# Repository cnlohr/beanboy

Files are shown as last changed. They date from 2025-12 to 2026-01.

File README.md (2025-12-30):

# beanboy

The beanboy is a handheld game system with 3 buttons, and an oled display.  It has the following specs:
 * Powered by a 9V Battery
 * 128x128 RB150-2828KSWKG01 SPI OLED display from Ronboe ($2.50)
 * 3 Silicone buttons with pressure sensitivity
 * TBD: Runtime
 * CH572 Main Processor
   * 240kB Flash
   * 12kB RAM
   * 60MHz
   * RISC-V rv32imbc processor
   * 2.4GHz iSLER radio comms

(Early drafts, not ready yet)

## Installation / getting started

Follow these instructions: [https://github.com/cnlohr/ch32fun/wiki](https://github.com/cnlohr/ch32fun/wiki)

## Graphics API

The bean boy uses a monochrome 128x128 display.

### Input

You get "pressures" for button 1, button 2, button 3, and the battery level. (For now, just print the values to the screen, we will be changing the levels)

```c
	uint32_t pressures[4];
	BeanBoyReadPressures( pressures );
```

### Sprites

Have .png files in `sprites/` folder, then on compile, they will turn into the object name itself, when you say `make clean firmware.elf`

```c
void RenderBSprite( const bsprite * spr, int outx, int outy );
```

For instance if you have `sprites/bubble.png`, you can call:

```c
	RenderBSprite( &bubble, x, y );
```

You can use purple or actual transparency to indicate transparent, then use white or black.

### Basic Drawing

Graphics APIs are from [the ch32v003 ssd1306 driver](https://github.com/cnlohr/ch32fun/blob/master/extralibs/ssd1306.h)

```c
#define SSD1306_W 128
#define SSD1306_H 128

void ssd1306_drawPixel(uint32_t x, uint32_t y, int color);
void ssd1306_xorPixel(uint32_t x, uint32_t y);
void ssd1306_drawImage(uint32_t x, uint32_t y, const unsigned char* input, uint32_t width, uint32_t height, uint32_t color_mode);
void ssd1306_drawFastVLine(int32_t x, int32_t y, int32_t h, uint32_t color);
void ssd1306_drawFastHLine(uint32_t x, uint32_t y, uint32_t w, uint32_t color);
void ssd1306_drawLine(int x0, int y0, int x1, int y1, uint32_t color);
void ssd1306_drawCircle(int x, int y, int radius, int color);
void ssd1306_fillCircle(int x, int y, int radius, int color);
void ssd1306_drawRect(int32_t x, int32_t y, uint32_t w, uint32_t h, uint32_t color);
void ssd1306_fillRect(uint32_t x, uint32_t y, uint8_t w, uint32_t h, uint32_t color);
void ssd1306_xorrect(uint8_t x, uint8_t y, uint8_t w, uint8_t h);
void ssd1306_drawchar(uint8_t x, uint8_t y, uint8_t chr, uint8_t color);
void ssd1306_drawstr(uint8_t x, uint8_t y, char *str, uint8_t color);
void ssd1306_drawchar_sz(uint8_t x, uint8_t y, uint8_t chr, uint8_t color, font_size_t font_size);
void ssd1306_drawstr_sz(uint8_t x, uint8_t y, char *str, uint8_t color, font_size_t font_size);
```

### Wireless API

```c
// call these
void ISLERSetup( int channel ); 
void ISLERSend( uint8_t message, int messageLength );

struct MyGameStruct
{
	uint32_t id;
	uint8_t something;
} __attribute__((packed));

void ISLERCallback( uint8_t * txmac, uint8_t * message, int messageLength, int rssi )
{
	struct MyGameStruct * st = (struct MyGameStruct*)message;

	if( messageLength < sizeof( struct MyGameStruct ) )
		return;

	printf( "%d\n", st->something );
}

void main()
{
	ISLERSetup( 9 );

	struct MyGameStruct st;
	st.id = 0x1234778a; // Some ID so you don't get confused with other BLE-messages.
	st.something = 5;

	ISLERSend( &st, sizeof( st ) );
}
```

## TODO

TODO:

1. ~~Build up two beanboys~~
2. ~~Check to see if the radio code works.~~
3. ~~Make sprite import code.~~
4. ~~Add transparency code.~~
5. ~~Add API for comms~~
6. Add networking to emu
7. Add button debouncing
8. Add compression to sprites
9. Add sprite rotation maybe?
10. Add sprite scaling maybe?
11. "Pass the puffer"  "Hot Potato with puffer fish"
  a. Choose between 2 and 6 players
  b. Randomly assign X amount of passes.
  c. number of passes remaining is unknown.
12. Shut the box.
  a. Rules too complicated for me to write here.

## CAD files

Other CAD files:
firmware/test/teapot.obj
firmware/test/donut.obj
firmware/test/bunny.obj
firmware/test/bean.obj

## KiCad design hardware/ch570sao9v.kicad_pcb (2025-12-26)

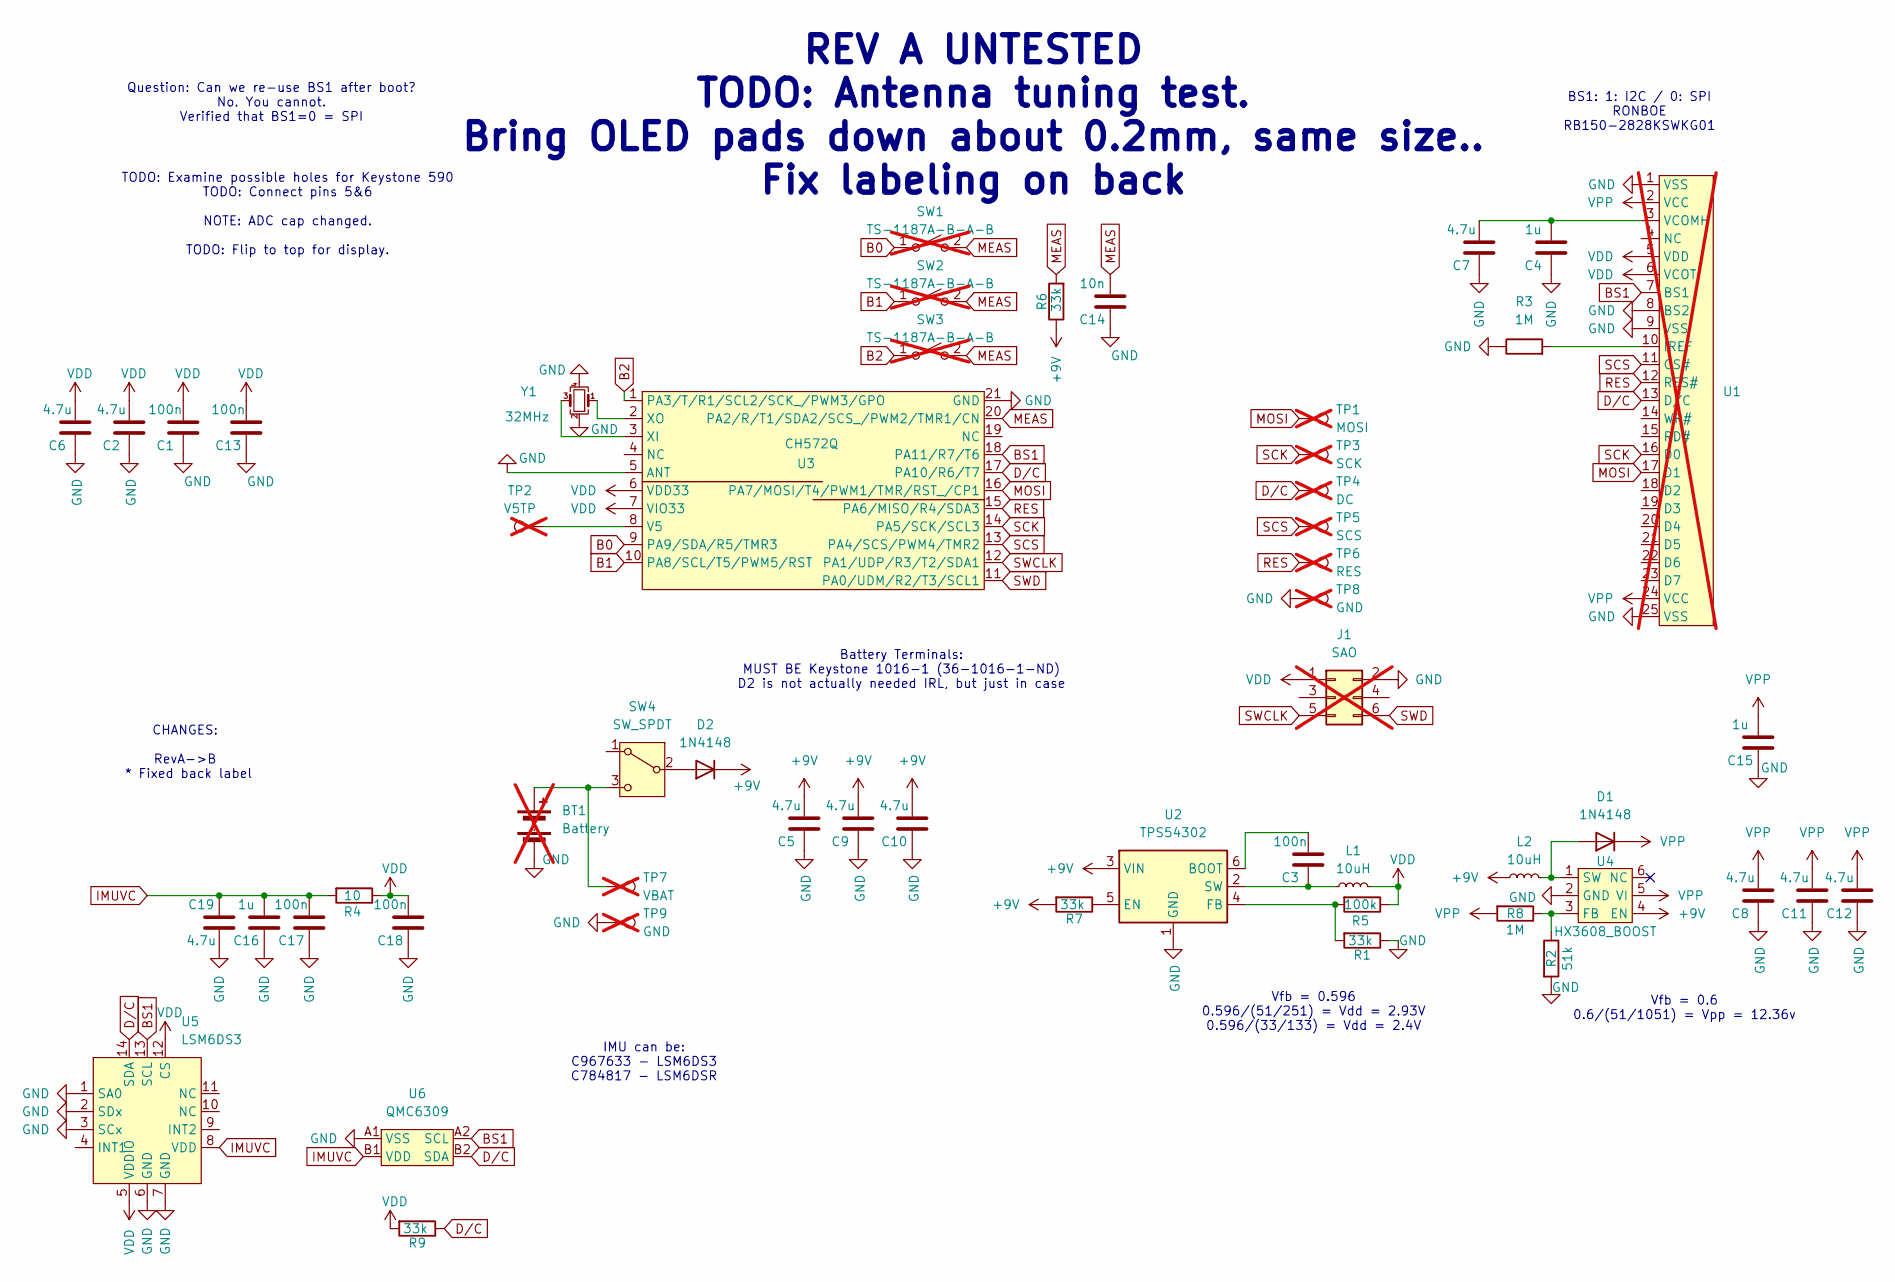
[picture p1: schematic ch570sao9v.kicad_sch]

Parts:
BT1: Battery; not fitted
C1, C3, C13, C17, C18: 100n; R_0402_1005Metric; LCSC C307331
C2, C5, C6, C7, C8, C9, C10, C11, C12, C19: 4.7u; C_1206_3216Metric; LCSC C29823
C4, C15, C16: 1u; R_0402_1005Metric; LCSC C52923
C14: 10n; R_0402_1005Metric; LCSC C15195
D1, D2: 1N4148; D_SOD-323; LCSC C2128
J1: SAO; PinHeader_2x03_P2.54mm_Vertical_SMD; not fitted
L1, L2: 10uH; L_1008_2520Metric; LCSC C37428
R1, R6, R7, R9: 33k; R_0402_1005Metric_COMPACT; LCSC C25779
R2: 51k; R_0402_1005Metric_COMPACT; LCSC C25794
R3, R8: 1M; R_0402_1005Metric_COMPACT; LCSC C26083
R4: 10; R_0402_1005Metric_COMPACT; LCSC C25077
R5: 100k; R_0402_1005Metric_COMPACT; LCSC C25741
SW1, SW2, SW3: TS-1187A-B-A-B; BTC007_Button_Silicone; not fitted
SW4: SW_SPDT; SW_SPDT_PCM12; LCSC C3008585
TP1: MOSI; TestPoint_Pad_D1.0mm; not fitted
TP2: V5TP; TestPoint_Pad_D1.0mm; not fitted
TP3: SCK; TestPoint_Pad_D1.0mm; not fitted
TP4: DC; TestPoint_Pad_D1.0mm; not fitted
TP5: SCS; TestPoint_Pad_D1.0mm; not fitted
TP6: RES; TestPoint_Pad_D1.0mm; not fitted
TP7: VBAT; TestPoint_Pad_D1.0mm; LCSC C6063943; not fitted
TP8: GND; TestPoint_Pad_D1.0mm; not fitted
TP9: GND; TestPoint_Pad_D1.0mm; LCSC C6063943; not fitted
U1: RB150-2828KSWKG01; not fitted
U2: TPS54302; SOT-23-6; LCSC C311983
U3: CH572Q; QFN-20-1EP_3x3mm_P0.4mm_EP1.65x1.65mm; LCSC C46597863
U4: HX3608_BOOST; SOT-23-6; LCSC C296278
U5: LSM6DS3; LGA-14_3x2.5mm_P0.5mm_LayoutBorder3x4y_EVEN_PADS; LCSC C784817
U6: QMC6309; WLP-4_0.83x0.83mm_P0.4mm; LCSC C5439871
Y1: 32MHz; Crystal_SMD_2016-4Pin_2.0x1.6mm; LCSC C37635323

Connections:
+9V: C5.1, C9.1, C10.1, D2.1 (K), L2.1, R6.1, R7.2, U2.3 (VIN), U4.4 (EN)
B0: SW1.1 (A), U3.9 (PA9/SDA/R5/TMR3)
B1: SW2.1 (A), U3.10 (PA8/SCL/T5/PWM5/RST)
B2: SW3.1 (A), U3.1 (PA3/T/R1/SCL2/SCK_/PWM3/GPO)
BS1: U1.7 (BS1), U3.18 (PA11/R7/T6), U5.13 (SCL), U6.A2 (SCL)
D/C: R9.1, TP4.1, U1.13 (D/C), U3.17 (PA10/R6/T7), U5.14 (SDA), U6.B2 (SDA)
GND: BT1.2 (-), C1.2, C2.2, C4.2, C5.2, C6.2, C7.2, C8.2, C9.2, C10.2, C11.2, C12.2, C13.2, C14.2, C15.2, C16.2, C17.2, C18.2, C19.1, J1.2, R1.1, R2.2, R3.1, TP8.1, TP9.1, U1.1 (VSS), U1.8 (BS2), U1.9 (VSS), U1.25 (VSS), U2.1 (GND), U3.5 (ANT), U3.21 (GND), U4.2 (GND), U5.1 (SA0), U5.2 (SDx), U5.3 (SCx), U5.6 (GND), U5.7 (GND), U6.A1 (VSS), Y1.2, Y1.4
IMUVC: C16.1, C17.1, C19.2, R4.2, U5.8 (VDD), U6.B1 (VDD)
MEAS: C14.1, R6.2, SW1.2 (B), SW2.2 (B), SW3.2 (B), U3.20 (PA2/R/T1/SDA2/SCS_/PWM2/TMR1/CN)
MOSI: TP1.1, U1.17 (D1), U3.16 (PA7/MOSI/T4/PWM1/TMR/RST_/CP1)
unnamed: BT1.1 (+), SW4.3 (C), TP7.1
unnamed: D1.2 (A), L2.2, U4.1 (SW)
unnamed: D2.2 (A), SW4.2 (B)
unnamed: R3.2, U1.10 (IREF)
unnamed: C4.1, C7.1, U1.3 (VCOMH)
unnamed: C3.1, U2.6 (BOOT)
unnamed: R7.1, U2.5 (EN)
unnamed: R1.2, R5.2, U2.4 (FB)
unnamed: C3.2, L1.1, U2.2 (SW)
unnamed: TP2.1, U3.8 (V5)
unnamed: U3.3 (XI), Y1.3
unnamed: U3.2 (XO), Y1.1
unnamed: R2.1, R8.1, U4.3 (FB)
RES: TP6.1, U1.12 (RES#), U3.15 (PA6/MISO/R4/SDA3)
SCK: TP3.1, U1.16 (D0), U3.14 (PA5/SCK/SCL3)
SCS: TP5.1, U1.11 (CS#), U3.13 (PA4/SCS/PWM4/TMR2)
SWCLK: J1.5, U3.12 (PA1/UDP/R3/T2/SDA1)
SWD: J1.6, U3.11 (PA0/UDM/R2/T3/SCL1)
VDD: C1.1, C2.1, C6.1, C13.1, C18.1, J1.1, L1.2, R4.1, R5.1, R9.2, U1.5 (VDD), U1.6 (VCOT), U3.6 (VDD33), U3.7 (VIO33), U5.5 (VDDIO), U5.12 (CS)
VPP: C8.1, C11.1, C12.1, C15.1, D1.1 (K), R8.2, U1.2 (VCC), U1.24 (VCC), U4.5 (VI)

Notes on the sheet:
REV A UNTESTED TODO: Antenna tuning test. Bring OLED pads down about 0.2mm, same size.. Fix labeling on back
TODO: Examine possible holes for Keystone 590 TODO: Connect pins 5&6 NOTE: ADC cap changed. TODO: Flip to top for display.
Question: Can we re-use BS1 after boot? No. You cannot. Verified that BS1=0 = SPI
IMU can be: C967633 - LSM6DS3 C784817 - LSM6DSR
Vfb = 0.596 0.596/(51/251) = Vdd = 2.93V 0.596/(33/133) = Vdd = 2.4V
Vfb = 0.6 0.6/(51/1051) = Vpp = 12.36v
CHANGES: RevA->B * Fixed back label
Battery Terminals: MUST BE Keystone 1016-1 (36-1016-1-ND) D2 is not actually needed IRL, but just in case
BS1: 1: I2C / 0: SPI RONBOE RB150-2828KSWKG01

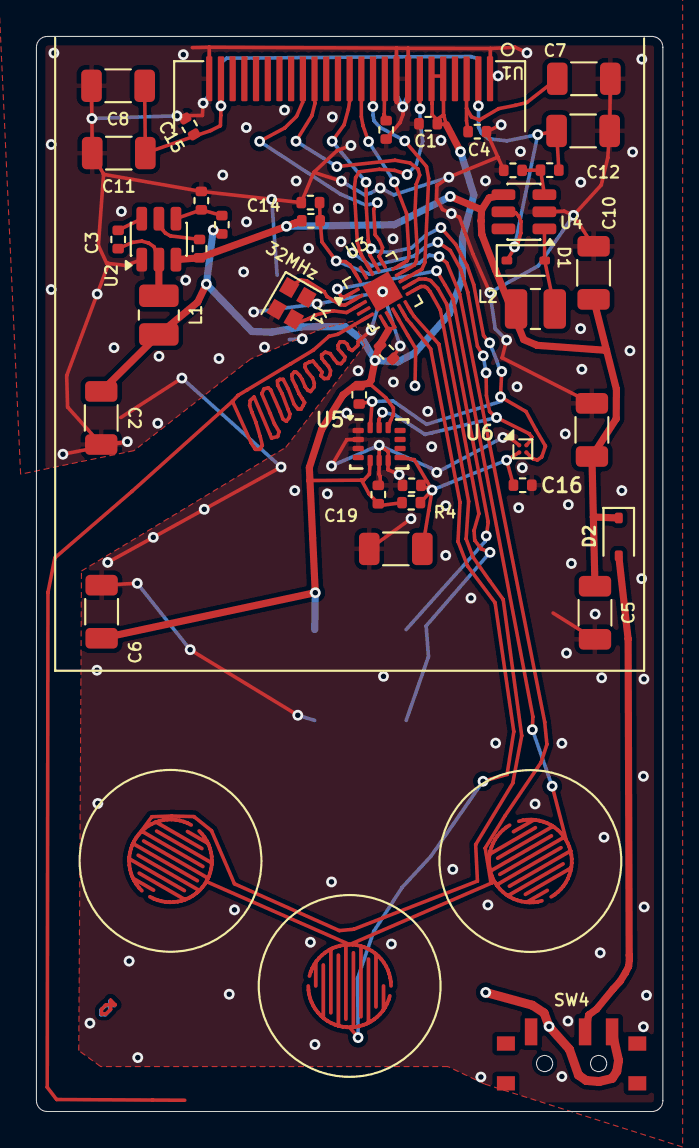
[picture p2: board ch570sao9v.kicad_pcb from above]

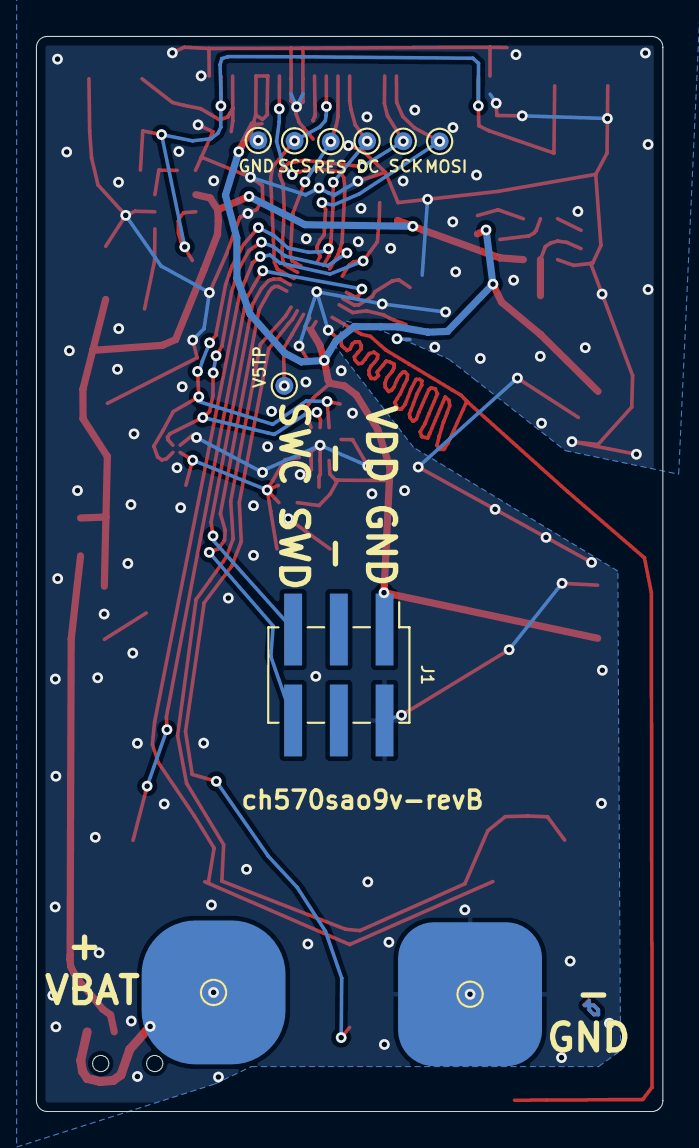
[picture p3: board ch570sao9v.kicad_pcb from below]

Board: 2 copper layers, 34.8 x 59.7 mm, 53 parts (10 on the bottom side), 30 nets.

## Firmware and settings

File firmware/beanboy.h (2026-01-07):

#ifndef _BEANBOY_H
#define _BEANBOY_H

// Forward declaration to push code into __HIGH_CODE which is really fast.
void ssd1306_drawPixel(uint32_t x, uint32_t y, int color) __HIGH_CODE;


#include "fixedmath.h"

/////////////////////////////////////////////////////////////////////////////////////////////////
/////////////////////////////////////////////////////////////////////////////////////////////////
// misc functions.

static inline void Reboot() __attribute__((noreturn));
static inline void Reboot()
{
	asm volatile( ".option push\n.option norelax\njr x0\n.option pop" );
	__builtin_unreachable();
}


/////////////////////////////////////////////////////////////////////////////////////////////////
/////////////////////////////////////////////////////////////////////////////////////////////////
// iSLER support
//
// BLE-like interface.

#if 0

#define ISLER_CALLBACK ISLER_BEANBOY_INTERNAL_CALLBACK
static void ISLER_BEANBOY_INTERNAL_CALLBACK();
#include "iSLER.h"
#define PHY_MODE       PHY_1M
#define ACCESS_ADDRESS 0x8E89BED6 // the "BED6" address for BLE advertisements

void ISLERCallback( uint8_t * txmac, uint8_t * message, int messageLength, int rssi );

uint8_t iSLERChannel;

static void ISLER_BEANBOY_INTERNAL_CALLBACK()
{
	// The chip stores the incoming frame in LLE_BUF, defined in extralibs/iSLER.h
	uint8_t *frame = (uint8_t*)LLE_BUF;
	if( !iSLERCRCOK() ) return;

	int rssi = ReadRSSI();
	int len = frame[0];
	ISLERCallback( frame+2, frame+10, len+4, rssi );
}

static void ISLERSetup( int channel )
{
	iSLERChannel = channel;
	RFCoreInit(LL_TX_POWER_6_DBM);
	Frame_RX(ACCESS_ADDRESS, channel, PHY_MODE);
}

static void ISLERSend( const void * message, int messageLength )
{
	__attribute__((aligned(4)))  uint8_t pkt_tx[messageLength+10];
	pkt_tx[0] = 0x02;
	pkt_tx[1] = 10+messageLength;
	memcpy( pkt_tx+2, (uint32_t*)ROM_CFG_MAC_ADDR, 6 );
	//memset( pkt_tx+2, 0xff, 6 );
	pkt_tx[8] = 0xff; // Normally should be 0x03, 0x19, 0x00, 0x00 for BLE
	pkt_tx[9] = 0xff; 
	memcpy( pkt_tx+10, message, messageLength );

	Frame_TX(ACCESS_ADDRESS, pkt_tx, messageLength+10, iSLERChannel, PHY_MODE);
	Frame_RX(ACCESS_ADDRESS, iSLERChannel, PHY_MODE);
}


#endif



const uint8_t * GetSelfMAC() { return (const uint8_t*)ROM_CFG_MAC_ADDR; }


/////////////////////////////////////////////////////////////////////////////////////////////////
/////////////////////////////////////////////////////////////////////////////////////////////////
// Auxiliary rendering sources bsprite
//
// This drawing function is very slow.  Consider optimizing.
//
static void RenderBSprite( const bsprite * spr, int outx, int outy ) __attribute__ ((noinline));
static void RenderBSprite( const bsprite * spr, int outx, int outy )
{
	int sw = spr->w;
	int sh = spr->h;
	int x, y;
	const uint32_t * bin = &spr->data[0];
	for( y = 0; y < sh; y++, outy++ )
	{
		uint8_t * bout = &ssd1306_buffer[(outy>>3)*SSD1306_W + outx];
		int boutshift = outy&7;
		int boutshiftmaskinv = ~(1<<boutshift);
		int tx = outx;
		int group;
		if( outy < 0 )
		{
			bin += sw;
			continue;
		}
		else if( outy >= SSD1306_H )
		{
			break;
		}

		for( group = 0; group < sw; group++ )
		{
			uint32_t input = *(bin++);
			for( x = 0; x < 16; x++, tx++, input >>= 1 )
			{
				if( tx < 0 || tx >= SSD1306_W ) continue;
				if( input & 1 )
				{
					bout[x] = ( bout[x] & boutshiftmaskinv ) | (((input>>16)&1)<< ( boutshift));
				}
			}
			bout += 16;
		}
	}
}
/////////////////////////////////////////////////////////////////////////////////////////////////
/////////////////////////////////////////////////////////////////////////////////////////////////
// FakeDC
//
// Fake digital-to-analog, by looking at the time constant on a capcaitor
// and waiting for the scmitt trigger flip.
//

#define CAPACITANCE 0.00000001
#define RESISTANCE  33000.0
#define VREF 1.75
#define FIXEDPOINT_SCALE 100

volatile uint32_t lastfifo = 0;
volatile uint32_t frameentropy = 0;

void TMR1_IRQHandler(void) __attribute__((interrupt))  __attribute__((section(".highcode")));
void TMR1_IRQHandler(void)
{
	R8_TMR_INT_FLAG = 2;
	lastfifo = R32_TMR_FIFO;
	funPinMode( PA2, GPIO_ModeOut_PP_20mA );
}


// The timing on the setup has to be tight.
void EventRelease(void) __attribute__((section(".highcode"))) __attribute__((noinline));
void EventRelease(void)
{
	R8_TMR_CTRL_MOD = 0b00000010; // Reset Timer
	R8_TMR_CTRL_MOD = 0b11000101; // Capture mode rising edge
	funPinMode( PA2, GPIO_ModeIN_Floating );
}

static void SetupADC(void)
{
	R8_TMR_CTRL_MOD = 0b00000010; // All clear
	R32_TMR_CNT_END = 0x03FFFFFF; // Maximum possible counter size.
	R8_TMR_CTRL_MOD = 0b11000101; // Capture mode rising edge
	R8_TMR_INTER_EN = 0b10; // Capture event.

	R16_PIN_ALTERNATE_H |= 1<<6; // Map PA2 to CAP1 (could be PA7, PA4, or PA9) (see RB_TMR_PIN)

	NVIC_EnableIRQ(TMR1_IRQn);
	__enable_irq();

	funPinMode( PA2, GPIO_ModeOut_PP_20mA );
}

static void BeanBoyReadPressures( uint32_t * pressures )
{
	int btn = 0;
	for( btn = 0; btn < 4; btn++ )
	{
		// try GPIO_CFGLR_IN_PUPD, GPIO_ModeIN_Floating, GPIO_CFGLR_OUT_10Mhz_PP as well
		funPinMode( PA3, GPIO_ModeIN_Floating );
		funPinMode( PA8, GPIO_ModeIN_Floating );
		funPinMode( PA9, GPIO_ModeIN_Floating );
		switch( btn )
		{
		case 0:
			funPinMode( PA8, GPIO_CFGLR_OUT_10Mhz_PP );
			funDigitalWrite( PA3, 1 );
			break;
		case 1:
			funPinMode( PA9, GPIO_CFGLR_OUT_10Mhz_PP );
			funDigitalWrite( PA8, 1 );
			break;
		case 2:
			funPinMode( PA3, GPIO_CFGLR_OUT_10Mhz_PP );
			funDigitalWrite( PA9, 1 );
			break;
		}

		uint32_t p;

		if( *((uint32_t*)0x4fff0000) == 0xaaaaaaaa )
		{
			p = *((uint32_t*)(0x4fff0004+4*btn));
		}
		else
		{
			lastfifo = 0;
			EventRelease();
			int to = 4000;
			while( !lastfifo && --to );

			#define COEFFICIENT (const uint32_t)(FUNCONF_SYSTEM_CORE_CLOCK*(RESISTANCE*CAPACITANCE)*VREF*FIXEDPOINT_SCALE+0.5)
			int r = lastfifo - 2; // 2 cycles back.
			int vtot = COEFFICIENT/r + ((const uint32_t)(VREF*FIXEDPOINT_SCALE));
			p = vtot - 70;
		}

		pressures[btn] = p;

		// Junky entropy.
		uint32_t fe = frameentropy;
		fe += p;
		fe ^= fe << 10;
		fe ^= fe << 21;
		frameentropy = fe;
	}
}

/////////////////////////////////////////////////////////////////////////////////////////////////


#define PIN_SDA PA10
#define PIN_SCL PA11
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

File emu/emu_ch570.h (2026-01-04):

#ifndef _CORE_H
#define _CORE_H

#include <stdint.h>

// For functions in this code.
uint32_t GetSTK(void);

//==============================================================================
// mini-rv32ima augmentations.
//==============================================================================

static inline void* ch570threadFn(void* v);
static inline uint32_t MINIRV32_LOAD4s(uint32_t ofs, uint32_t* rval, uint32_t* trap);
static inline uint16_t MINIRV32_LOAD2s(uint32_t ofs, uint32_t* rval, uint32_t* trap);
static inline uint8_t MINIRV32_LOAD1s(uint32_t ofs, uint32_t* rval, uint32_t* trap);
static inline int16_t MINIRV32_LOAD2_SIGNEDs(uint32_t ofs, uint32_t* rval, uint32_t* trap);
static inline int8_t MINIRV32_LOAD1_SIGNEDs(uint32_t ofs, uint32_t* rval, uint32_t* trap);

#define RAM_SIZE   0x3000
#define FLASH_SIZE 0x40000

extern uint32_t R32_PA_PU;
extern uint32_t R32_PA_PD_DRV;
extern uint32_t R32_PA_DIR;
extern uint32_t R32_PA_OUT;
extern uint32_t R32_PFIC_IENR1;
extern volatile int ch570runMode;
extern uint8_t ch570flash[FLASH_SIZE];
extern uint8_t ch570ram[RAM_SIZE];
extern struct MiniRV32IMAState ch570state;
extern volatile uint32_t pressures[4];

void Handle_R8_TMR_CTRL_MOD( uint8_t regset );
void Handle_R8_SPI_BUFFER( uint8_t regset );


uint32_t debugpc; // Debug PC

static int CHPLoad(uint32_t address, uint32_t* regret, int size);
static int CHPStore(uint32_t address, uint32_t regret, int size);

#define MINI_RV32_RAM_SIZE		(0x20000000 + RAM_SIZE)
#define MINIRV32_RAM_IMAGE_OFFSET 0x00000000
#define MINIRV32WARN(x...)		fprintf(stderr, x)
#define MINIRV32_MMIO_RANGE(n)	((0x40000000 <= (n) && (n) < 0x50000000)) || (0xe0000000 <= (n) && (n) < 0xe000ffff)

// These should not be accessable.
#define MINIRV32_HANDLE_MEM_STORE_CONTROL(addy, val) CHPStore(addy, val, 4);
#define MINIRV32_HANDLE_MEM_LOAD_CONTROL(addy, val)  CHPLoad(addy, &val, 4);

#define RAMOFS 0x20000000

#define MINIRV32_CUSTOM_MEMORY_BUS

#define MINIRV32_STORE4(ofs, val)						  \
	if (ofs < FLASH_SIZE - 3)							  \
	{													  \
		*(uint32_t*)(ch570flash + ofs) = val;		   \
	}													  \
	else if (ofs >= RAMOFS && ofs < RAMOFS + RAM_SIZE - 3) \
	{													  \
		*(uint32_t*)(ch570ram + ofs - RAMOFS) = val;	\
	}													  \
	else												   \
	{													  \
		if (CHPStore(ofs, val, 4))						 \
		{												  \
			trap = (7 + 1);								\
			rval = ofs;									\
		}												  \
	}
#define MINIRV32_STORE2(ofs, val)						  \
	if (ofs < FLASH_SIZE - 1)							  \
	{													  \
		*(uint16_t*)(ch570flash + ofs) = val;		   \
	}													  \
	else if (ofs >= RAMOFS && ofs < RAMOFS + RAM_SIZE - 1) \
	{													  \
		*(uint16_t*)(ch570ram + ofs - RAMOFS) = val;	\
	}													  \
	else												   \
	{													  \
		if (CHPStore(ofs, val, 2))						 \
		{												  \
			trap = (7 + 1);								\
			rval = ofs;									\
		}												  \
	}
#define MINIRV32_STORE1(ofs, val)						  \
   { \
	if (ofs < FLASH_SIZE - 0)							  \
	{													  \
		*(uint8_t*)(ch570flash + ofs) = val;			\
	}													  \
	else if (ofs >= RAMOFS && ofs < RAMOFS + RAM_SIZE - 0) \
	{													  \
		*(uint8_t*)(ch570ram + ofs - RAMOFS) = val;	 \
	}													  \
	else												   \
	{													  \
		if (CHPStore(ofs, val, 1))						 \
		{												  \
			trap = (7 + 1);								\
			rval = ofs;									\
		}												  \
	} }
static inline uint32_t MINIRV32_LOAD4s(uint32_t ofs, uint32_t* rval, uint32_t* trap)
{
	uint32_t tmp = 0;
	if (ofs < FLASH_SIZE - 3)
	{
		tmp = *(uint32_t*)(ch570flash + ofs);
	}
	else if (ofs >= RAMOFS && ofs < RAMOFS + RAM_SIZE - 3)
	{
		tmp = *(uint32_t*)(ch570ram + ofs - RAMOFS);
	}
	else
	{
		if (CHPLoad(ofs, &tmp, 4))
		{
			*trap = (7 + 1);
			*rval = ofs;
		}
	}
	return tmp;
}
static inline uint16_t MINIRV32_LOAD2s(uint32_t ofs, uint32_t* rval, uint32_t* trap)
{
	uint16_t tmp = 0;
	if (ofs < FLASH_SIZE - 1)
	{
		tmp = *(uint16_t*)(ch570flash + ofs);
	}
	else if (ofs >= RAMOFS && ofs < RAMOFS + RAM_SIZE - 1)
	{
		tmp = *(uint16_t*)(ch570ram + ofs - RAMOFS);
	}
	else
	{
		if (CHPLoad(ofs, (uint32_t*)&tmp, 2))
		{
			*trap = (7 + 1);
			*rval = ofs;
		}
	}
	return tmp;
}
static inline uint8_t MINIRV32_LOAD1s(uint32_t ofs, uint32_t* rval, uint32_t* trap)
{
	uint8_t tmp = 0;
	if (ofs < FLASH_SIZE - 0)
	{
		tmp = *(uint8_t*)(ch570flash + ofs);
	}
	else if (ofs >= RAMOFS && ofs < RAMOFS + RAM_SIZE - 0)
	{
		tmp = *(uint8_t*)(ch570ram + ofs - RAMOFS);
	}
	else
	{
		if (CHPLoad(ofs, (uint32_t*)&tmp, 1))
		{
			*trap = (7 + 1);
			*rval = ofs;
		}
	}
	return tmp;
}
static inline int16_t MINIRV32_LOAD2_SIGNEDs(uint32_t ofs, uint32_t* rval, uint32_t* trap)
{
	int16_t tmp = 0;
	if (ofs < FLASH_SIZE - 1)
	{
		tmp = *(int16_t*)(ch570flash + ofs);
	}
	else if (ofs >= RAMOFS && ofs < RAMOFS + RAM_SIZE - 1)
	{
		tmp = *(int16_t*)(ch570ram + ofs - RAMOFS);
	}
	else
	{
		if (CHPLoad(ofs, (uint32_t*)&tmp, -2))
		{
			*trap = (7 + 1);
			*rval = ofs;
		}
	}
	return tmp;
}
static inline int8_t MINIRV32_LOAD1_SIGNEDs(uint32_t ofs, uint32_t* rval, uint32_t* trap)
{
	int8_t tmp = 0;
	if (ofs < FLASH_SIZE - 0)
	{
		tmp = *(int8_t*)(ch570flash + ofs);
	}
	else if (ofs >= RAMOFS && ofs < RAMOFS + RAM_SIZE - 0)
	{
		tmp = *(int8_t*)(ch570ram + ofs - RAMOFS);
	}
	else
	{
		if (CHPLoad(ofs, (uint32_t*)&tmp, -1))
		{
			*trap = (7 + 1);
			*rval = ofs;
		}
	}
	return tmp;
}

#define MINIRV32_LOAD4(ofs)		MINIRV32_LOAD4s(ofs, &rval, &trap)
#define MINIRV32_LOAD2(ofs)		MINIRV32_LOAD2s(ofs, &rval, &trap)
#define MINIRV32_LOAD1(ofs)		MINIRV32_LOAD1s(ofs, &rval, &trap)
#define MINIRV32_LOAD2_SIGNED(ofs) MINIRV32_LOAD2_SIGNEDs(ofs, &rval, &trap)
#define MINIRV32_LOAD1_SIGNED(ofs) MINIRV32_LOAD1_SIGNEDs(ofs, &rval, &trap)

#define MINIRV32_HANDLE_TRAP_PC									 \
	switch (CSR(mtvec) & 3)										 \
	{															   \
		case 2:													 \
		case 0:													 \
			pc = (CSR(mtvec) - 4);								  \
			break;												  \
		case 1:													 \
			pc = (((CSR(mtvec) & ~3) + 4 * CSR(mcause)) - 4);	   \
			break;												  \
		case 3:													 \
			pc = ((MINIRV32_LOAD4((CSR(mtvec) & ~3) + 4 * 3)) /* - 4  I thought we needed this */); \
			break;												  \
	}

#define MINIRV32_ALIGNMENT 1

#define MINIRV32_IMPLEMENTATION

// https://riscv.github.io/riscv-isa-manual/snapshot/unprivileged/#_compressed_instruction_formats about 1/3 the way
// down. https://www.cs.sfu.ca/~ashriram/Courses/CS295/assets/notebooks/RISCV/RISCV_CARD.pdf
// This adds -C extension support to mini-rv32ima.
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

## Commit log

2025-12-07 Add skeleton project
    [ch570sao9v.kicad_pcb, ch570sao9v.kicad_sch]
2025-12-07 Update design
    [ch570sao9v.kicad_pcb, ch570sao9v.kicad_sch]
2025-12-11 Update to rev a
    [ch570sao9v.kicad_pcb, ch570sao9v.kicad_sch]
2025-12-12 Update rev a
    [ch570sao9v.kicad_pcb, ch570sao9v.kicad_sch]
2025-12-25 Bump design
    [ch570sao9v.kicad_pcb, ch570sao9v.kicad_sch]
2025-12-26 Update firmware with I2C stuff
2025-12-26 Add bean boy rev B
    [ch570sao9v.kicad_pcb]
2025-12-30 1. Update my stuff 2. Fix delta time
    [beanboy.h, custom_i2c.h, firmware.c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]
2025-12-31 Update system to enable wireless comms
2026-01-04 Working IMU math
2026-01-04 Oope switch menu back + I think my mode is done
2026-01-04 * Fix graphics performance * Make IMU work for example apps
    [bean.obj, bunny.obj]
2026-01-04 Remove extra printf
2026-01-04 Fixup some bugs in the IMU code and improve performance
    [beanboy.h, firmware.c, mode_test.h]
2026-01-05 Add donut to models
    [donut.obj]
2026-01-05 Groundwork laid for blackjack
2026-01-05 Update mode test with teapot
    [teapot.obj]
2026-01-05 Dunno why but resetting caused issues for the OLED
    [mode_test.h]
2026-01-07 Ready to fix shutbox
    [mode_shutbox.h]
2026-01-07 Fix mode menu - don't overwrite data
    [firmware.c]
2026-01-15 Remove firmware.experiment, and update design
    [ch570sao9v.kicad_sch]
